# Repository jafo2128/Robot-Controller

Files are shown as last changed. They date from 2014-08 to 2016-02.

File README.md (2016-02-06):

# Robot-Controller
Robot-Controller Shield for Wattuino Pro Mini.

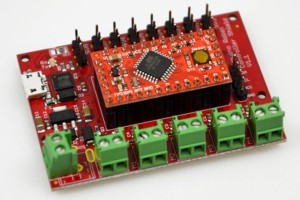
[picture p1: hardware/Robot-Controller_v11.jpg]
Robot-Controller (http://www.watterott.com/en/Robot-Controller)


## Shop
* [Robot-Controller Shield](http://www.watterott.com/en/Robot-Controller)
* [Robot-Controller Shield with Wattuino Pro Mini](http://www.watterott.com/en/Robot-Controller-with-Wattuino-Pro-Mini-5V/16MHz)

## Features
* [TI DRV8838](http://www.ti.com/product/drv8838) Motor Driver (2-11V 1.8A)
* [FTDI FT232R](http://www.ftdichip.com/Products/ICs/FT232R.htm) USB-UART Bridge (microUSB)
* Power MOSFET
* Extension Ports for Servo Motor or Sensors

## Hardware
* [Schematics + Layout](https://github.com/watterott/Robot-Controller/tree/master/hardware)

Finally words from us Archivers and Developers.. 

##### Donate

People from time to time wish to donate a little money. Donating won't get you anything special, other than a warm feeling inside, and possibly urge me to produce more freely available material for interesting projects. You can donate via [PayPal](https://www.paypal.com), just click [donate](https://www.paypal.com/cgi-bin/webscr?cmd=_s-xclick&hosted_button_id=3PXVSLXFBS45E) button available below - it will redirect you to the secured PayPal page where you can provide donation amount (there is no minimal value). Any donations are apreciated greatly, and we thank you all in advance for your support along the ways..



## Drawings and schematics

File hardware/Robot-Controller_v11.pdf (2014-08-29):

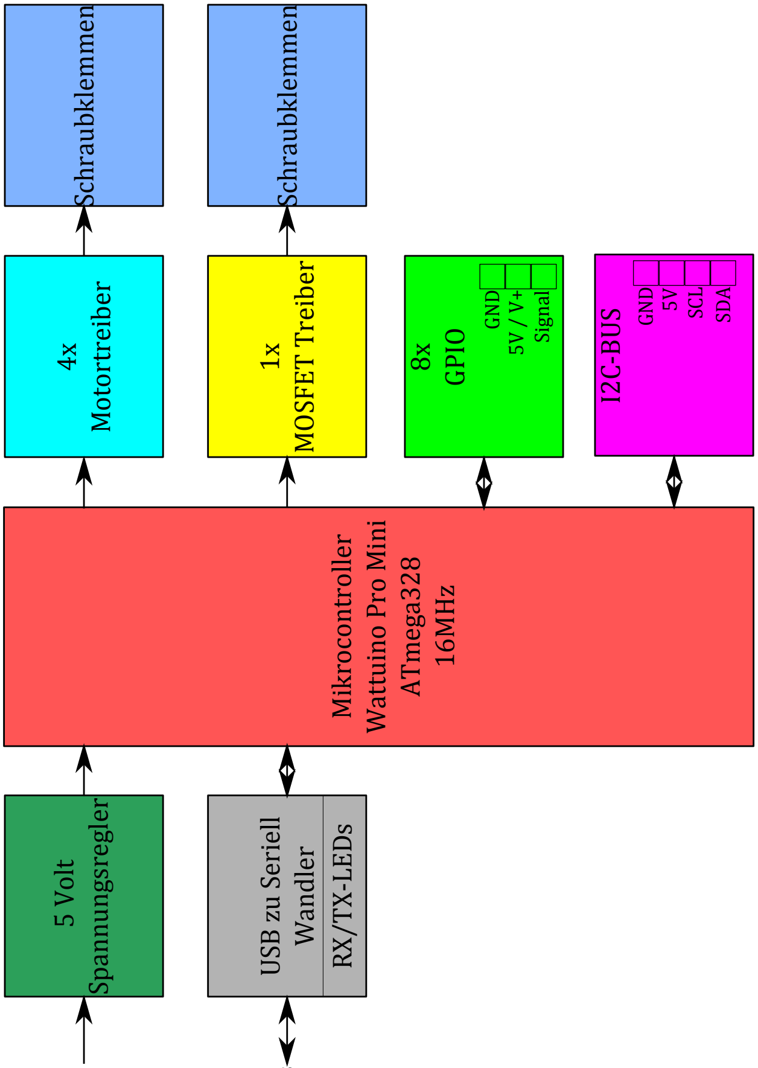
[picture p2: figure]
Mikrocontroller; Wattuino Pro Mini; ATmegaCN8; +6MHz; 5 Volt; Spannungsregler; USB zu Seriell; Wandler; Motortreiber; MOSFET Treiber; RXITXDLEDs; GPIO; Schraubklemmen; 5V I V- GND; Signal; INCDBUS; GND; SCL; SDA

V-

# USB

# Robot Controller Shield for Wattuino Pro Mini

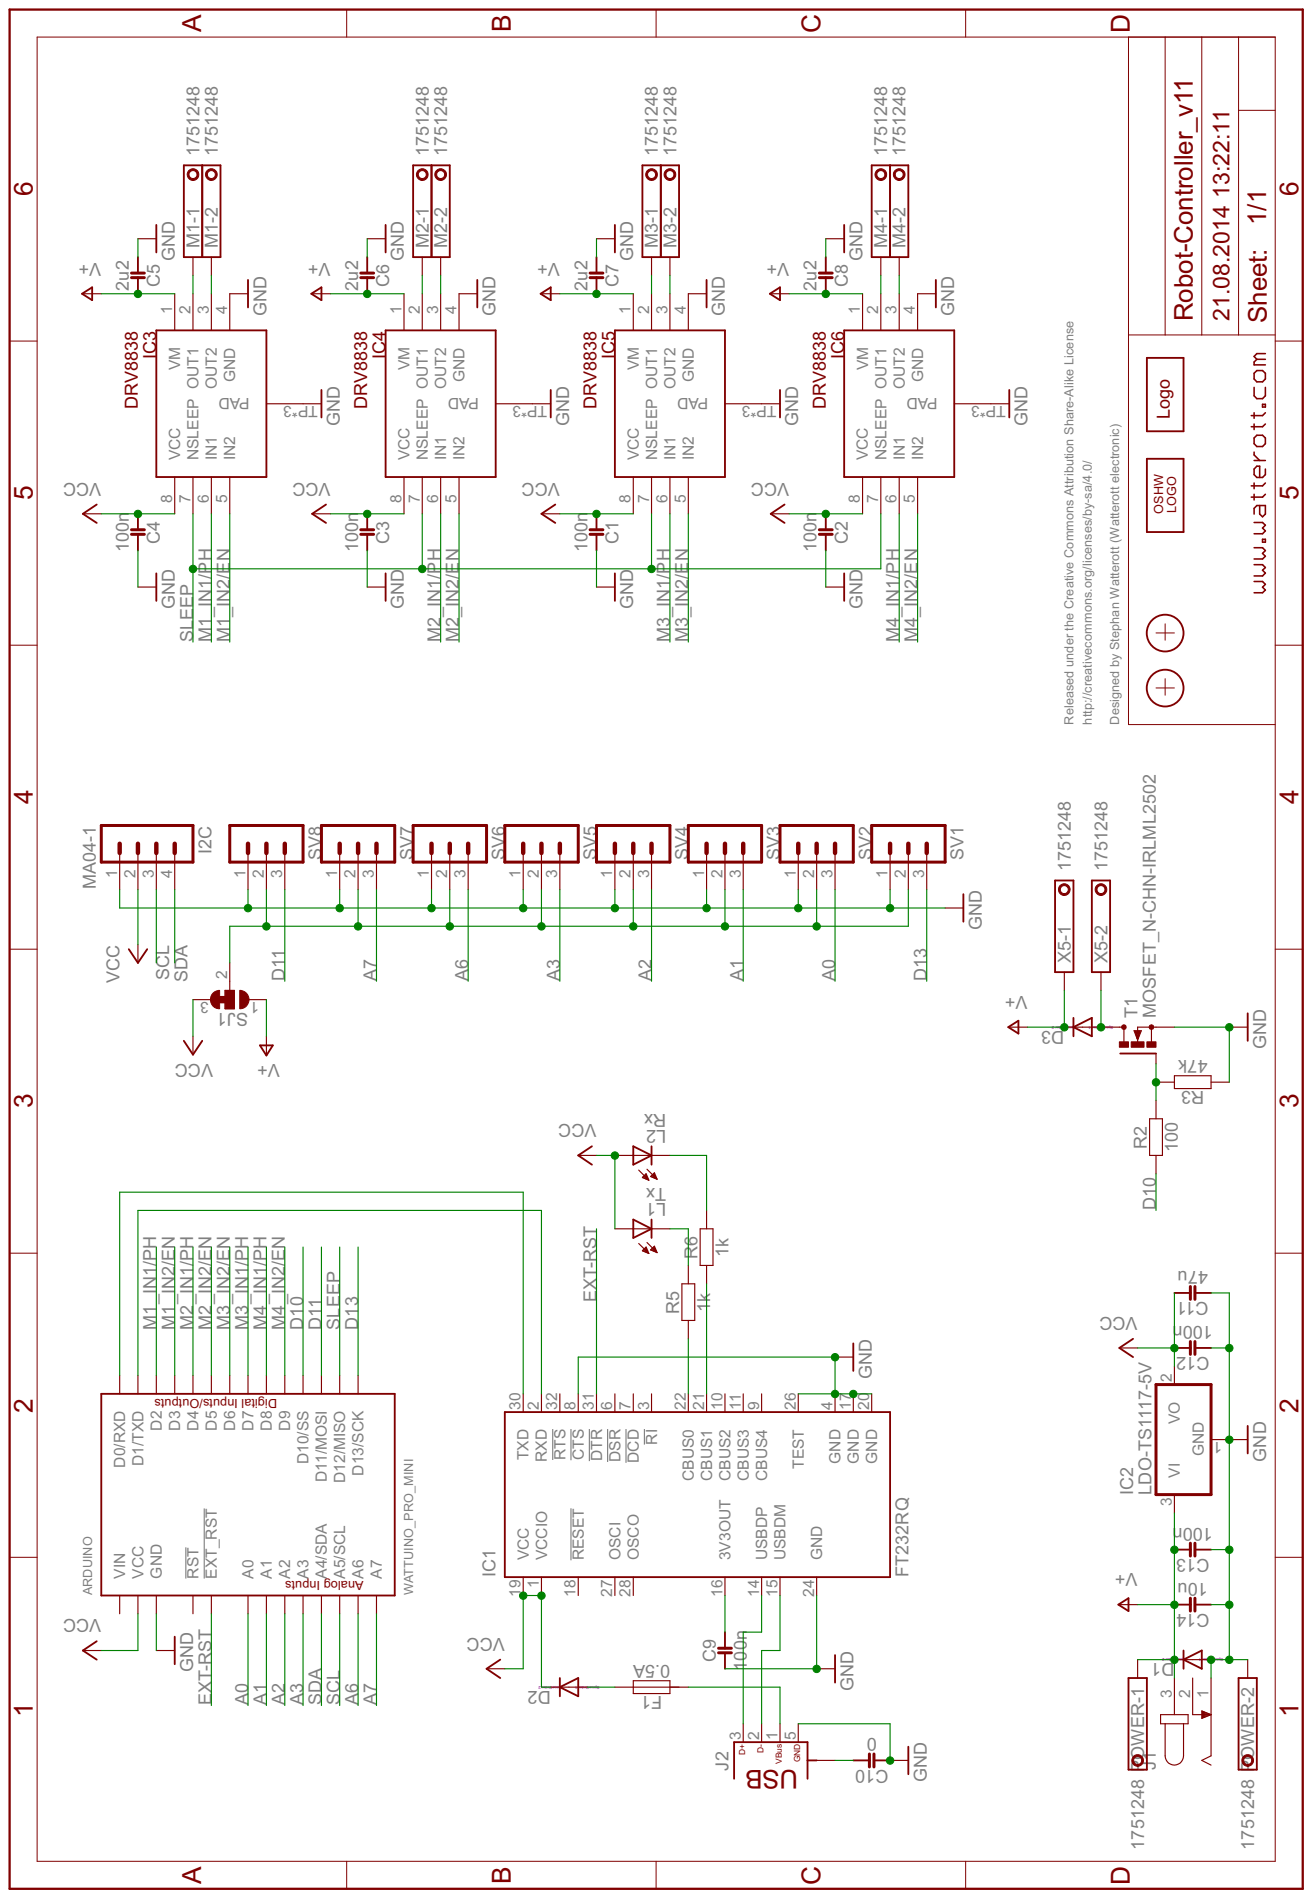
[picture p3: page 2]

Released under the Creative Commons Attribution Share-Alike License

http://creativecommons.org/licenses/by-sa/4.0/ Designed by Stephan Watterott (Watterott electronic)

SLEEP M1_IN2/EN M1_IN2/EN M1_IN1/PH M1_IN1/PH

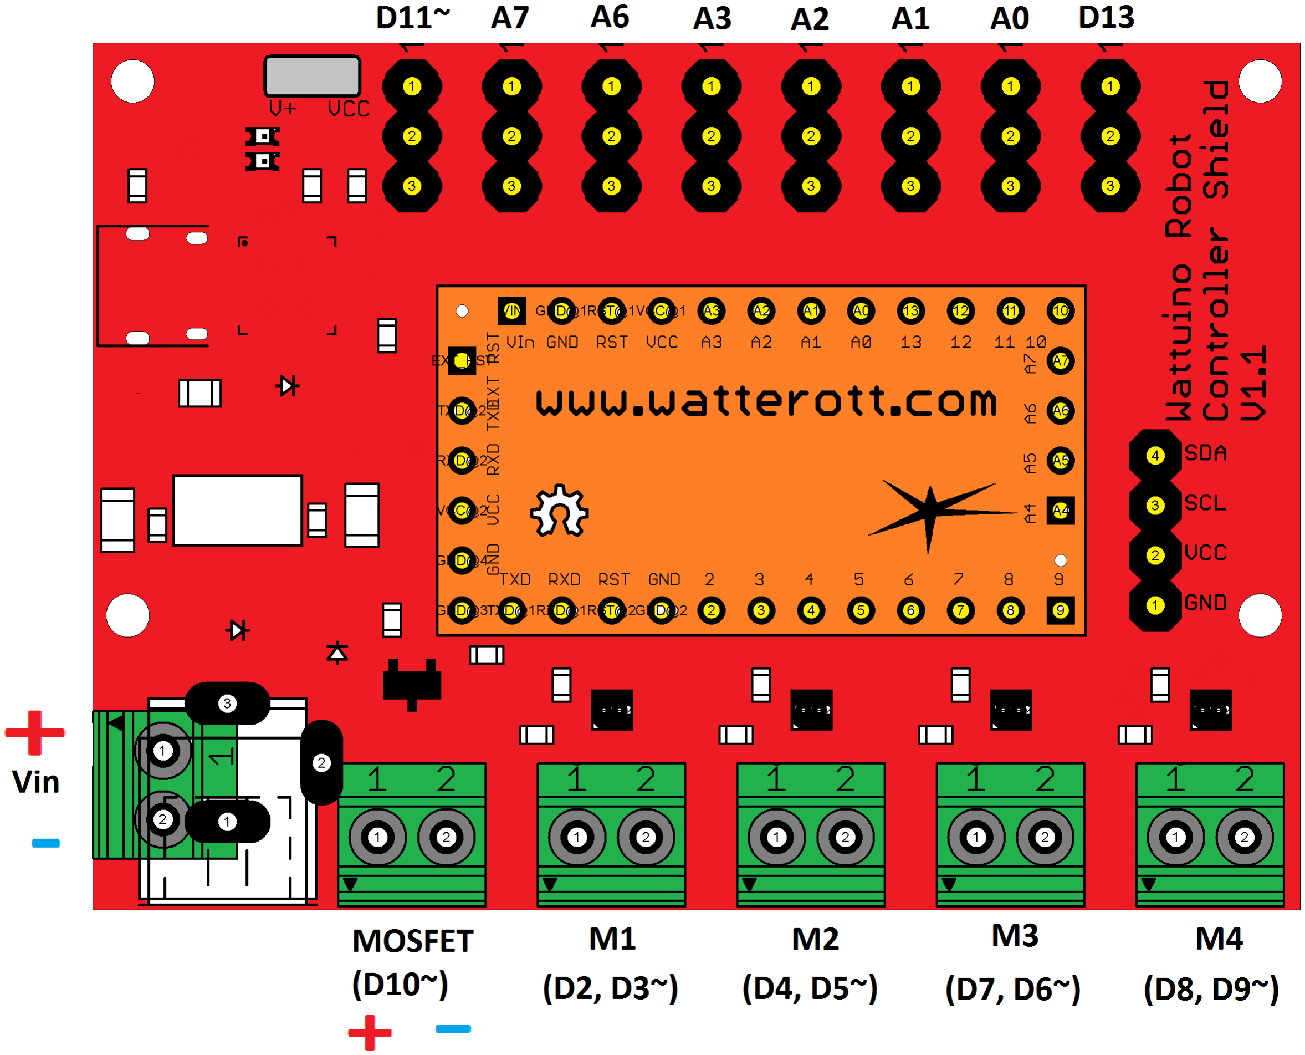
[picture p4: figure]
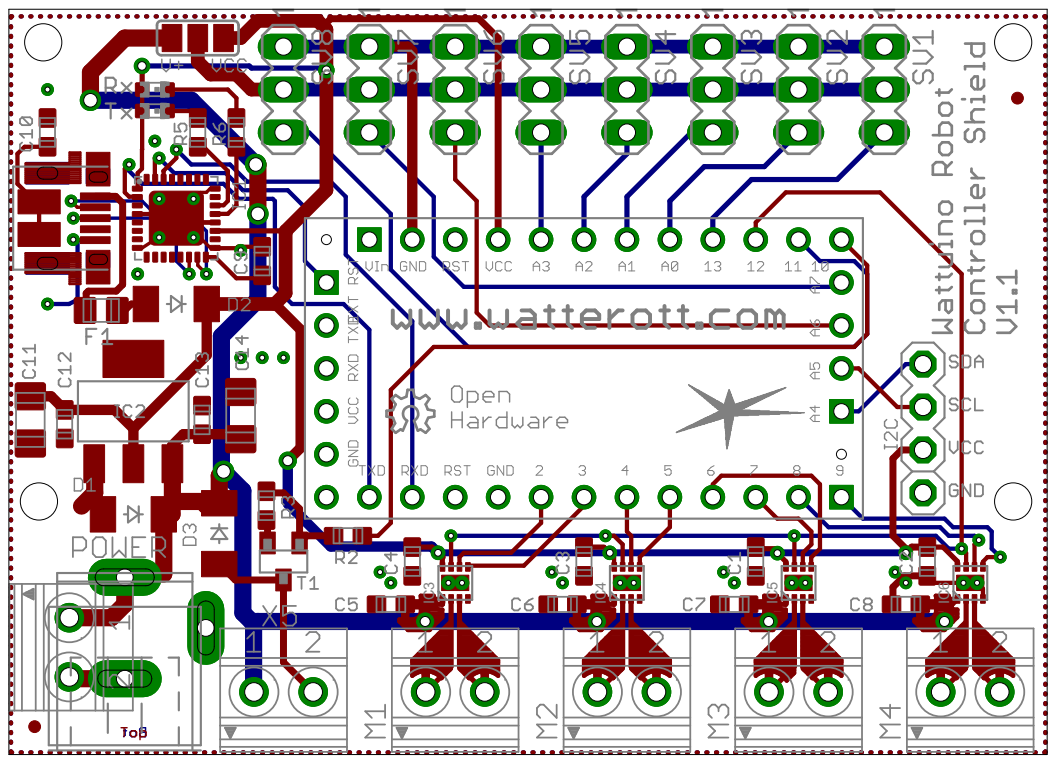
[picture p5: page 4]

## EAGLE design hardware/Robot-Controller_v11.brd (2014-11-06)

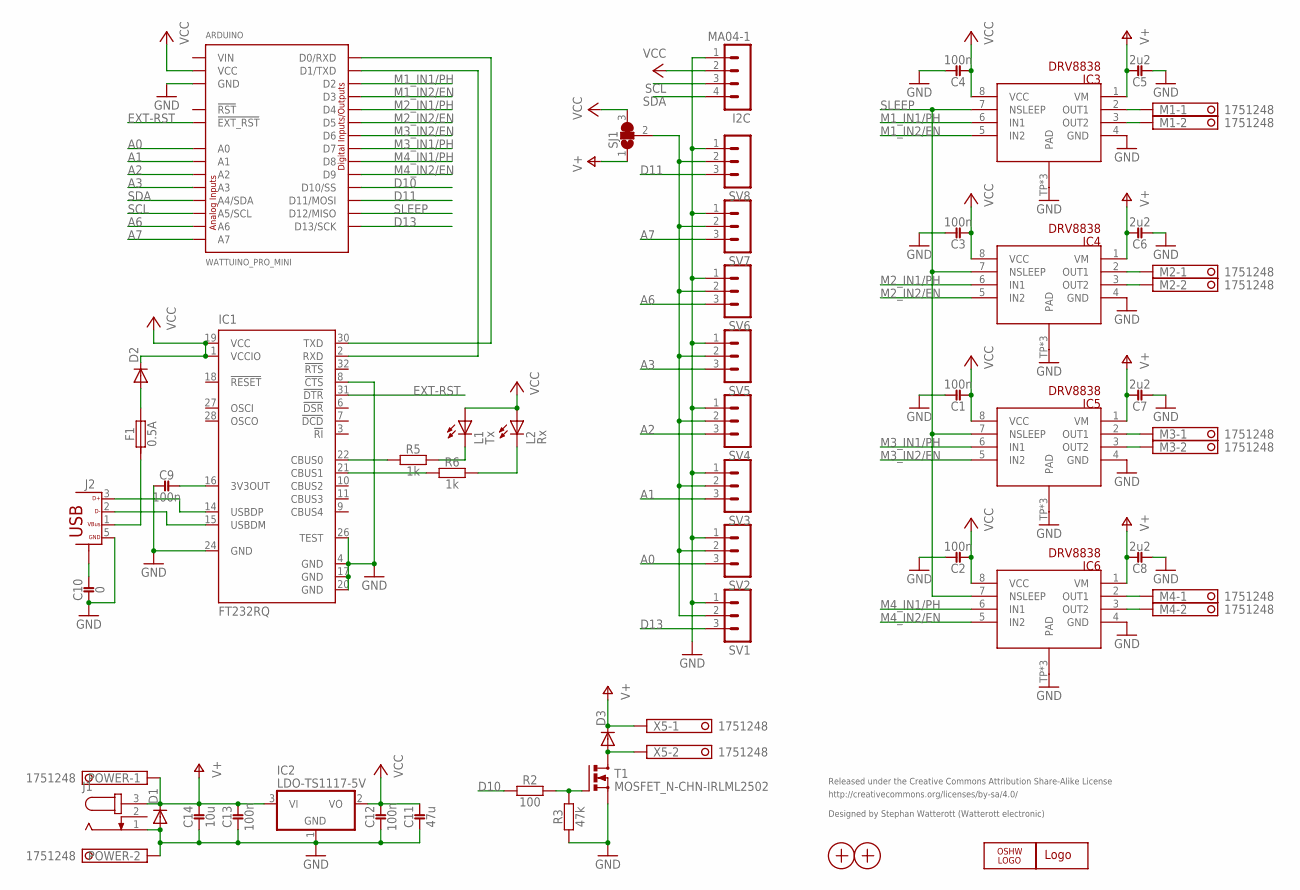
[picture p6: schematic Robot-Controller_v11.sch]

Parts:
ARDUINO: WATTUINO_PRO_MINI
C1, C2, C3, C4, C9, C12, C13: 100n; R0603
C5, C6, C7, C8: 2u2; R0603
C10: 0; R0603
C11: 47u; R1206
C14: 10u; R1206
D1, D2, D3: CGRM4001-G; SOD-123_MINI-SMA
F1: 0.5A; R0805
I2C: MA04-1
IC1: FT232RQ; QFN32
IC2: LDO-TS1117-5V; SOT223
IC3, IC4, IC5, IC6: DRV8838; WSON8
J1: DC-JACK""; DC-JACK
J2: USB10103594-0001LF; 10103594
L1: Tx; LED_0603
L2: Rx; LED_0603
LOGO2: OSHW_LOGOX0100; OSHW_6X100
LOGO3: LOGO-SPARK_PLACE; SPARK_TPLACE
M1, M2, M3, M4: 1751248
POWER: 1751248
R2: 100; R0603
R3: 47k; R0603
R5, R6: 1k; R0603
SJ1: SJ2W; SJ_2
SV1, SV2, SV3, SV4, SV5, SV6, SV7, SV8: MA03-1
T1: MOSFET_N-CHN-IRLML2502; SOT23
X1, X2: PASSER-07; PASSER_07MM
X5: 1751248

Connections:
A0: ARDUINO.A0, SV2.3
A1: ARDUINO.A1, SV3.3
A2: ARDUINO.A2, SV4.3
A3: ARDUINO.A3, SV5.3
A6: ARDUINO.A6, SV6.3
A7: ARDUINO.A7, SV7.3
D10: ARDUINO.10 (D10/SS), R2.1
D11: ARDUINO.11 (D11/MOSI), SV8.3
D13: ARDUINO.13 (D13/SCK), SV1.3
EXT-RST: ARDUINO.EXT_RST (!EXT_RST), IC1.31 (!DTR)
GND: ARDUINO.GND@1 (GND), C1.2, C2.2, C3.2, C4.2, C5.1, C6.1, C7.1, C8.1, C9.1, C10.1, C11.1, C12.1, C13.1, C14.1, D1.A, I2C.1, IC1.4 (GND), IC1.8 (!CTS), IC1.17 (GND), IC1.20 (GND), IC1.24 (GND), IC1.26 (TEST), IC2.1 (GND), IC3.4 (GND), IC3.TP (PAD), IC3.TP1 (PAD), IC3.TP2 (PAD), IC4.4 (GND), IC4.TP (PAD), IC4.TP1 (PAD), IC4.TP2 (PAD), IC5.4 (GND), IC5.TP (PAD), IC5.TP1 (PAD), IC5.TP2 (PAD), IC6.4 (GND), IC6.TP (PAD), IC6.TP1 (PAD), IC6.TP2 (PAD), J1.1, J2.5 (GND), POWER.2, R3.1, SV1.1, SV2.1, SV3.1, SV4.1, SV5.1, SV6.1, SV7.1, SV8.1, T1.2 (S)
M1_IN1/PH: ARDUINO.2 (D2), IC3.6 (IN1)
M1_IN2/EN: ARDUINO.3 (D3), IC3.5 (IN2)
M2_IN1/PH: ARDUINO.4 (D4), IC4.6 (IN1)
M2_IN2/EN: ARDUINO.5 (D5), IC4.5 (IN2)
M3_IN1/PH: ARDUINO.7 (D7), IC5.6 (IN1)
M3_IN2/EN: ARDUINO.6 (D6), IC5.5 (IN2)
M4_IN1/PH: ARDUINO.8 (D8), IC6.6 (IN1)
M4_IN2/EN: ARDUINO.9 (D9), IC6.5 (IN2)
unnamed: IC3.2 (OUT1), M1.1
unnamed: IC3.3 (OUT2), M1.2
unnamed: IC4.2 (OUT1), M2.1
unnamed: IC4.3 (OUT2), M2.2
unnamed: IC5.2 (OUT1), M3.1
unnamed: IC5.3 (OUT2), M3.2
unnamed: IC6.2 (OUT1), M4.1
unnamed: IC6.3 (OUT2), M4.2
unnamed: F1.1, J2.1 (VBUS)
unnamed: IC1.15 (USBDM), J2.2 (D-)
unnamed: R2.2, R3.2, T1.1 (G)
unnamed: C9.2, IC1.16 (3V3OUT)
unnamed: ARDUINO.RXD@1 (D0/RXD), IC1.30 (TXD)
unnamed: D3.A, T1.3 (D), X5.2
unnamed: IC1.14 (USBDP), J2.3 (D+)
unnamed: ARDUINO.TXD@1 (D1/TXD), IC1.2 (RXD)
unnamed: IC1.22 (CBUS0), R5.1
unnamed: IC1.21 (CBUS1), R6.1
unnamed: SJ1.2, SV1.2, SV2.2, SV3.2, SV4.2, SV5.2, SV6.2, SV7.2, SV8.2
unnamed: C10.2, J2.P$6 (SHIELD), J2.P$7 (SHIELD)
unnamed: D2.A, F1.2
unnamed: L1.C, R5.2
unnamed: L2.C, R6.2
SCL: ARDUINO.A5 (A5/SCL), I2C.3
SDA: ARDUINO.A4 (A4/SDA), I2C.4
SLEEP: ARDUINO.12 (D12/MISO), IC3.7 (NSLEEP), IC4.7 (NSLEEP), IC5.7 (NSLEEP), IC6.7 (NSLEEP)
V+: C5.2, C6.2, C7.2, C8.2, C13.2, C14.2, D1.C, D3.C, IC2.3 (VI), IC3.1 (VM), IC4.1 (VM), IC5.1 (VM), IC6.1 (VM), J1.3, POWER.1, SJ1.1, X5.1
VCC: ARDUINO.VCC@1 (VCC), C1.1, C2.1, C3.1, C4.1, C11.2, C12.2, D2.C, I2C.2, IC1.1 (VCCIO), IC1.19 (VCC), IC2.2 (VO), IC3.8 (VCC), IC4.8 (VCC), IC5.8 (VCC), IC6.8 (VCC), L1.A, L2.A, SJ1.3
VIN: ARDUINO.VIN

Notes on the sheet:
Released under the Creative Commons Attribution Share-Alike License
http://creativecommons.org/licenses/by-sa/4.0/
Designed by Stephan Watterott (Watterott electronic)

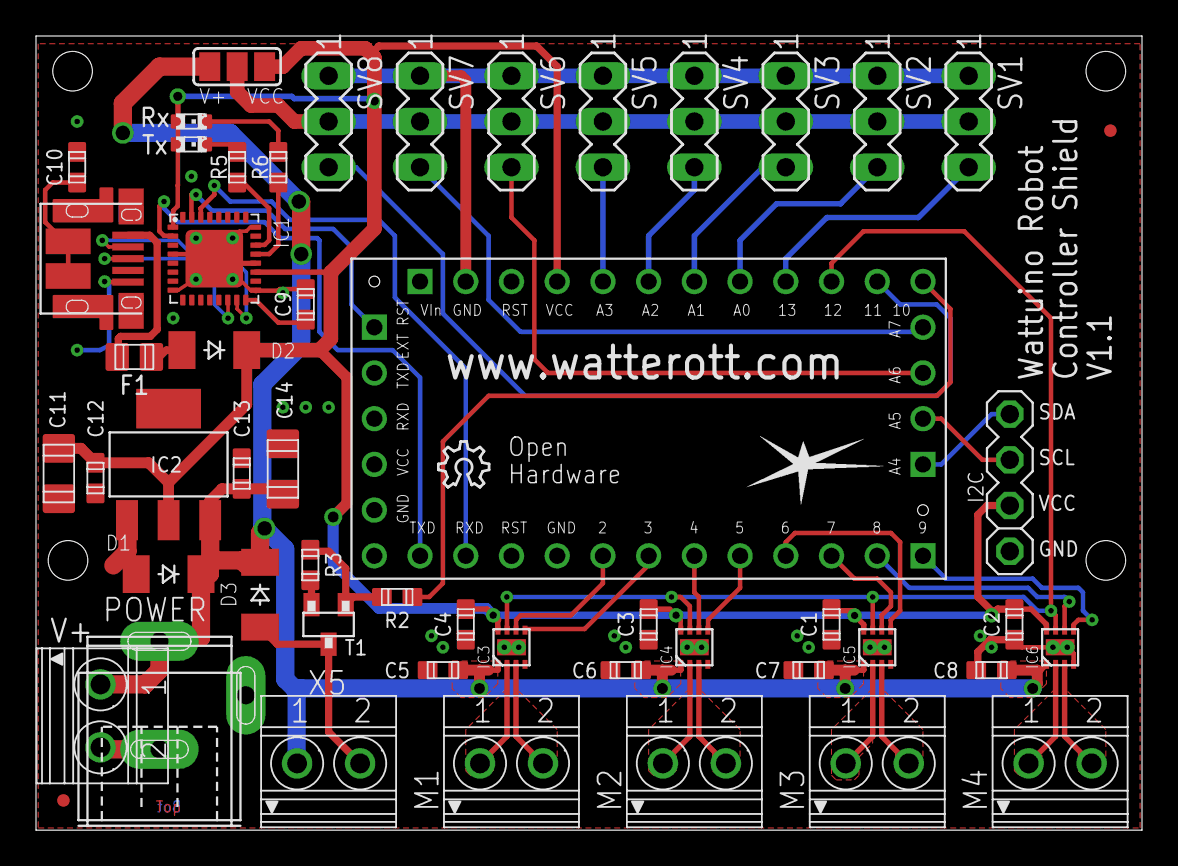
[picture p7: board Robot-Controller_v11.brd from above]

Board: 2 copper layers, 61.4 x 44.1 mm, 54 parts (0 on the bottom side), 47 nets.

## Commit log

2014-08-23 added layout and schematics
    [Robot-Controller_v11.brd, Robot-Controller_v11.sch]
2014-08-29 updated layout and schematics
    [Robot-Controller_v11.brd]
2014-11-06 cleaned up schematics and layout
    [Robot-Controller_v11.brd, Robot-Controller_v11.sch]
2015-08-21 changed path structure
    [Robot-Controller_v11.brd, Robot-Controller_v11.sch]

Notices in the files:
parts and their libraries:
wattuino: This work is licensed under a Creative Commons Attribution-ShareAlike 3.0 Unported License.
